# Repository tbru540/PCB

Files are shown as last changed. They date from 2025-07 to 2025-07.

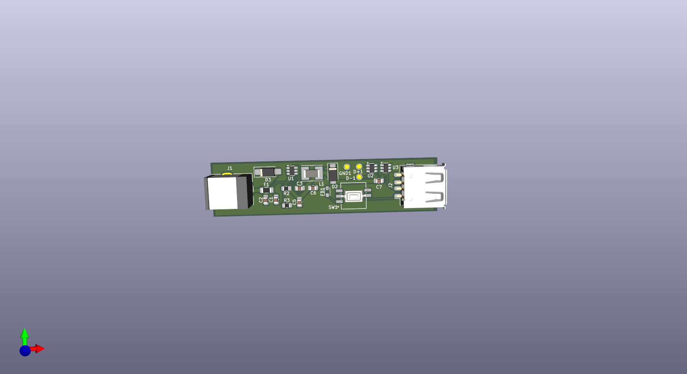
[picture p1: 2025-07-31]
5V_AA_V3.png

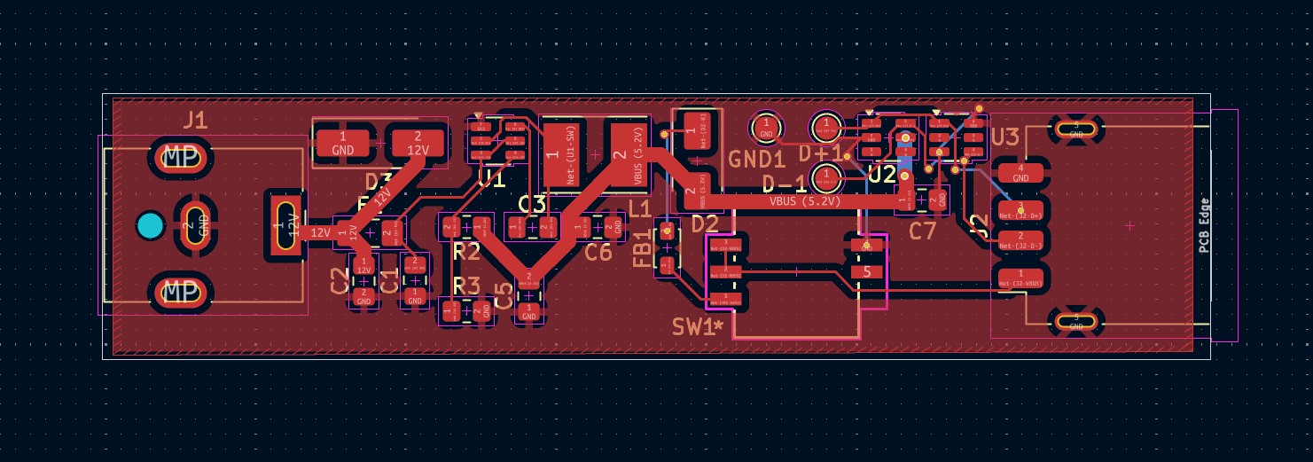
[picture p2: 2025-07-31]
PCB.jpg

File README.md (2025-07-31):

# PCB
AA Charger Custom PCB

I completely redesigned the board, incorporating a dedicated charging port chip to automatically manipulate D+ and D- for each type of device, as well as incorporated a more modern buck converter into the board itself instead of using an external buck converter module. I've also incorporated a switch to enable power to the USB with a built in LED indiciator, a fuse for overcurrent protection, a TVS diode to protect against voltage spikes, as well as a ferrite bead to suppress EMI. This board was created using KiCad 9.0. 

The files above contain the file to the schematic and the PCB. Also, I've included pictures of the schematic, PCB, and 3D model for easier viewing. The 3D model is a PNG file, while the pictures of the schematic and PCB are JPG files.

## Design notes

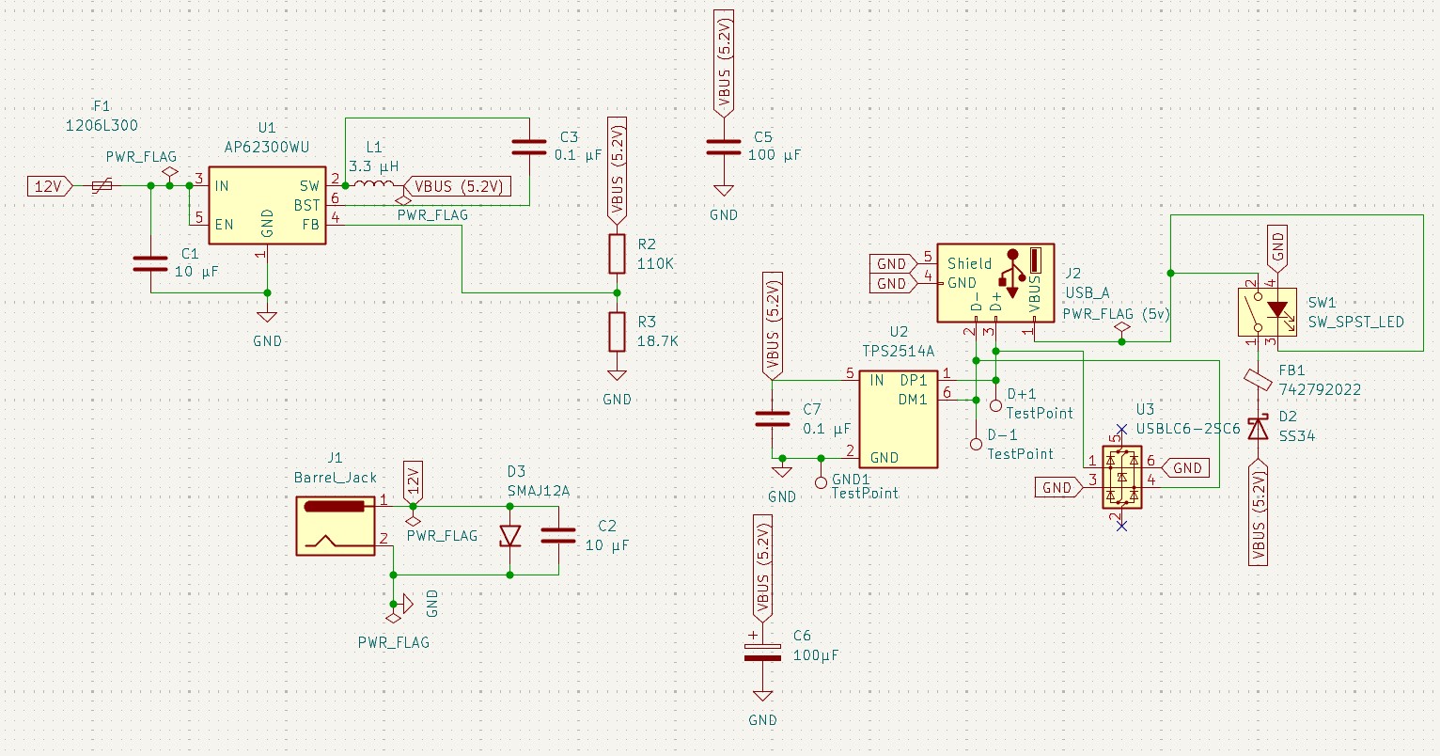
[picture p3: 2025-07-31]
Schematic.jpg

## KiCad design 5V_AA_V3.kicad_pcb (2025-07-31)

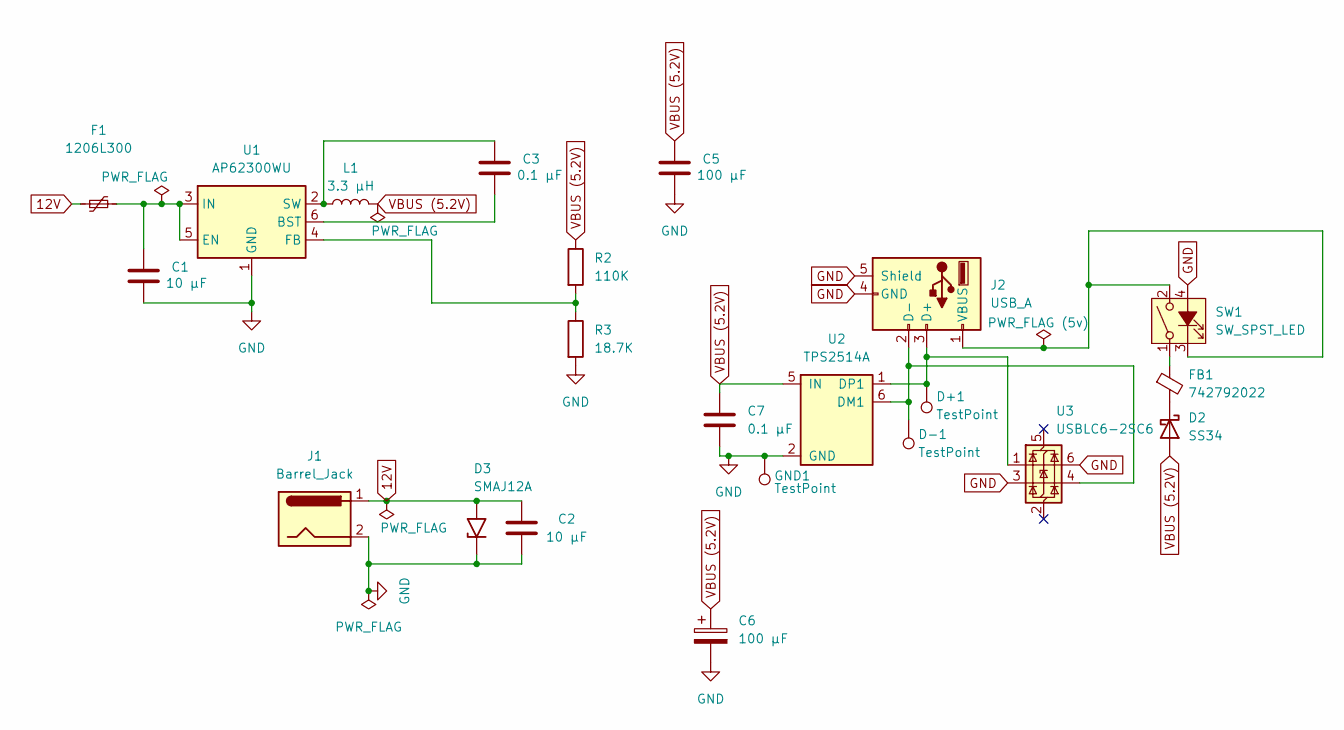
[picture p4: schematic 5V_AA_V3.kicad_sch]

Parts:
C1, C2: 10 µF; C_0805_2012Metric_Pad1.18x1.45mm_HandSolder
C3, C7: 0.1 µF; C_0805_2012Metric_Pad1.18x1.45mm_HandSolder
C5, C6: 100 µF; C_0805_2012Metric_Pad1.18x1.45mm_HandSolder
D2: SS34; D_SMA
D3: SMAJ12A; D_SMA_Handsoldering
D+1: TestPoint; TestPoint_Pad_D1.5mm
D-1: TestPoint; TestPoint_Pad_D1.5mm
F1: 1206L300; Fuse_1206_3216Metric_Pad1.42x1.75mm_HandSolder
FB1: 742792022; L_Walsin_WLFM201209x
GND1: TestPoint; TestPoint_Pad_D1.5mm
J1: Barrel_Jack; BarrelJack_CUI_PJ-063AH_Horizontal
J2: USB_A; USB_A_Receptacle_GCT_USB1046
L1: 3.3 µH; L_Taiyo-Yuden_NR-50xx_HandSoldering
R2: 110K; R_0805_2012Metric_Pad1.20x1.40mm_HandSolder
R3: 18.7K; R_0805_2012Metric_Pad1.20x1.40mm_HandSolder
SW1: SW_SPST_LED; SOP5_K8BU41_CNK
U1: AP62300WU; TSOT-23-6
U2: TPS2514A; SOT-23-6
U3: USBLC6-2SC6; SOT-23-6

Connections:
12V: C2.1, D3.2 (A2), F1.1, J1.1
GND: C1.1, C2.2, C5.1, C6.2, C7.2, D3.1 (A1), GND1.1, J1.2, J2.4 (GND), J2.5 (Shield), R3.2, SW1.4 (A), U1.1 (GND), U2.2 (GND), U3.3 (I/O2), U3.6 (I/O1)
unnamed: D2.1 (K), FB1.2
unnamed: FB1.1, SW1.1
unnamed: D+1.1, J2.3 (D+), U2.1 (DP1), U3.1 (I/O1)
unnamed: D-1.1, J2.2 (D-), U2.6 (DM1), U3.4 (I/O2)
unnamed: J2.1 (VBUS), SW1.2, SW1.3 (K)
unnamed: C3.1, U1.6 (BST)
unnamed: C1.2, F1.2, U1.3 (IN), U1.5 (EN)
unnamed: R2.2, R3.1, U1.4 (FB)
unnamed: C3.2, L1.1, U1.2 (SW)
VBUS (5.2V): C5.2, C6.1, C7.1, D2.2 (A), L1.2, R2.1, U2.5 (IN)

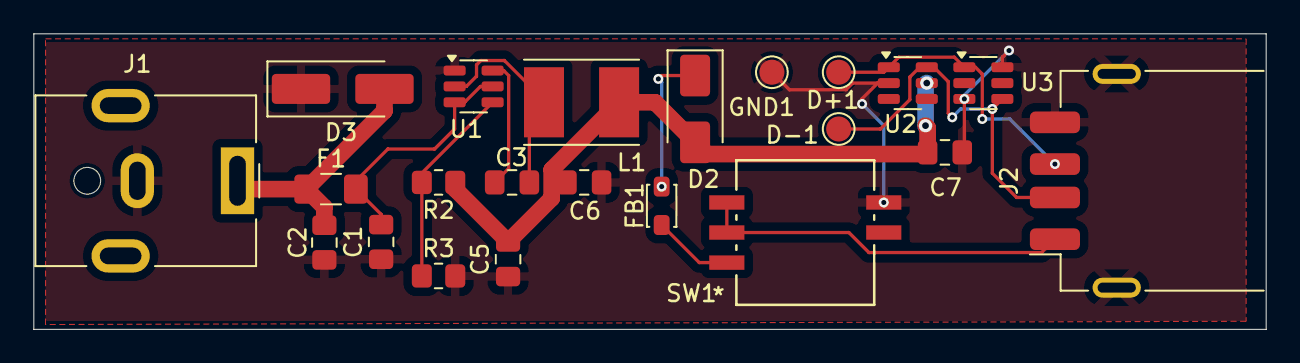
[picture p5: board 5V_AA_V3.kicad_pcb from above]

Board: 2 copper layers, 73.8 x 17.7 mm, 22 parts (0 on the bottom side), 12 nets.
